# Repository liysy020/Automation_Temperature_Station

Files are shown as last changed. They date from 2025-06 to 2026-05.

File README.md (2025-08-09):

A central monitor to all network temperature and humidity sensors. This project suitable for Comms room monitoring in business and home users.

Sensors runs over wifi. They report data to the server. Depends on the sensor type it can monitor the temperatore and humidity of outdoor and indoor environment. It can also have LCD display showing current time as display on your desk (I uploaded a simple 3D print model for the desk display verson).

The project needs ESP32 running with micro Python. Tested 3x different types of outdoor and indoor temperature and humidity sensors. A 2 x 16 LCD display (Optional).

The sensor will need to register to the server in order to obtain a rendom generated API key. Communication running over SSL provides a secure channel.

Email alert can be switched on to get notification when sensor detected value outside of your comfort zone settings.

The sensor can also trigger external application such as exhaust fan when alert value met.

Last but not least the server keeps 4 months data history of the sensors. The data can be display in graph views.

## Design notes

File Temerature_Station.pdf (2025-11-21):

# Temperature and Humidity Station

# Introduction

There are 2 parts in this project. The first one is to build an LCD display clock using ESP32, LCD or OLED module with temperature sensors. It will show the current date time and the sensor information. You can build as many temperature monitors and put that round your house, garage, back yard etc with different types of IoT sensors as you design.

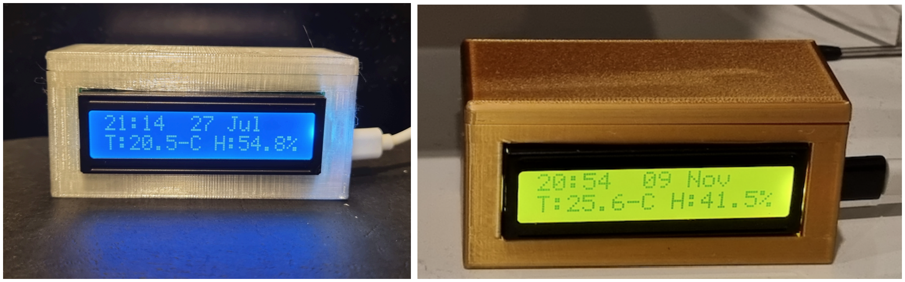
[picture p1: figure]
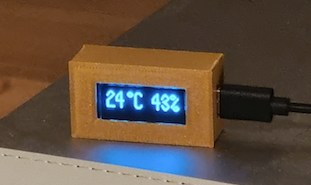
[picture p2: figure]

Part 2 is to build a server that collects all the sensor data and presents the latest sensor information such as temperature and humidity on a webserver. The ESP32 control board will send data every 2 mins using API calls. API Keys are stored on the server. Users can disable / enable any key resulting allow or reject the data from individual sensors. In addition, email notification can also be configured if temperature or humidity is outside of the comfort zone and trigger the power on/off of an electrical application via relay module

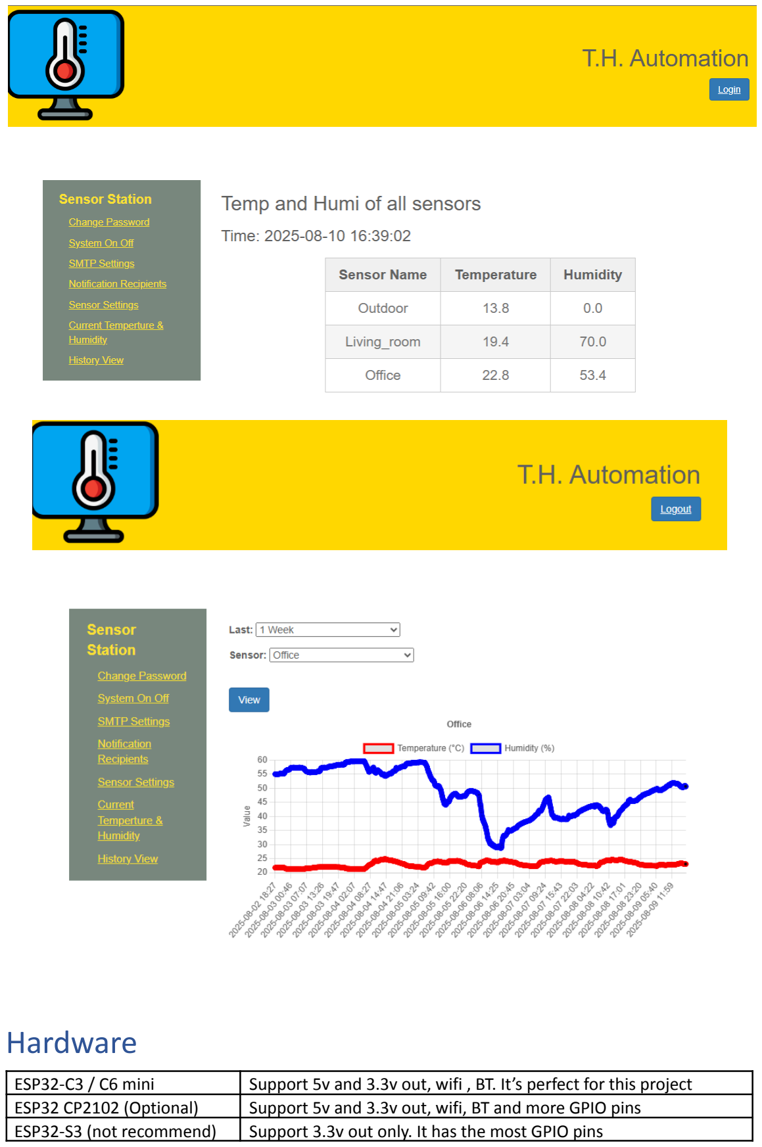
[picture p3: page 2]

# Hardware

ESP32-C3 / C6 mini | Support 5v and 3.3v out, wifi , BT. It’s perfect for this project
ESP32 CP2102 (Optional) | Support 5v and 3.3v out, wifi, BT and more GPIO pins
ESP32-S3 (not recommend) | Support 3.3v out only. It has the most GPIO pins

LCD1602 (Optional) | I2C 2 x 16 LCD display. 5V input
OLED 128 x 32 (Optional) | I2C 128 x32 OLES display. 3V input
DHT 11 (your pick) | Indoor temperature and humidity sensor / Cheap Input 3.3-5V / 0 – 50° C (± 2° C) / 20 – 90%RH (± 5%RH)
DHT 22 (your pick) | Temperature and humidity sensor Input 3.3-5V / -40 – 80 ° C (± 0.5° C) / 0 – 100%RH (± 2%)
DS18B20 (your pick) | Outdoor waterproof temperature sensor Input 3.3-5V / -55 – 125 ° C
Raspberry Pi 3b | 32Gb SD-card and Raspberry Lite OS
QC-3FF-S-Z | Power relay switch Input 5V / 10A 250vc or 15A 125vac

# Build the ESP32 and Sensors

## ESP32 Wiring - LCD and Temp Sensor

You will need to update the main.py file with the correct pin numbers according to the sensor and the LCD display you are going to use.

Below are the example values can be used / configured in the main.py for ESP32-CP2102 control board with LCD1602 display and DS18B20 temperature sensor

TEMP_PIN = 2

SDA_PIN = 21

SCL_PIN = 22

Another example for ESP32-3C, the SIG pin of the temperature sensor can go to ESP32’s GPIO 5. The LCD display SDA -> pin 8 and SCL -> pin 9

TEMP_PIN = 5

SDA_PIN = 8

SCL_PIN = 9

## Temperature Sensor Wiring (example)

DS18B20 can work on either 3v or 5v. I use 3v to reserve the 5v pin for LCD display

VCC <--> 3V, GND <--> Ground, SIG <--> GPIO 2

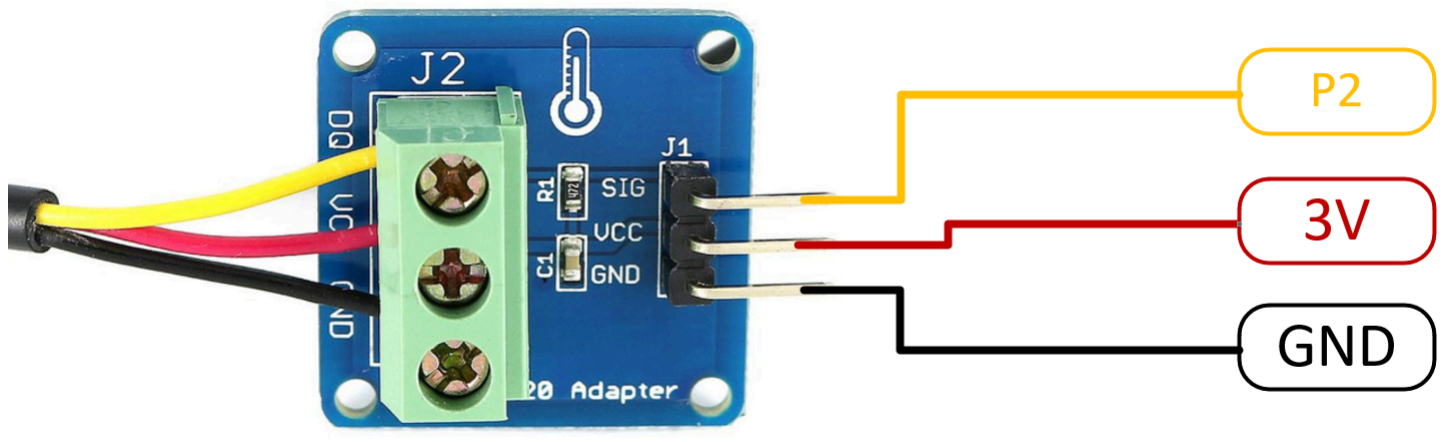
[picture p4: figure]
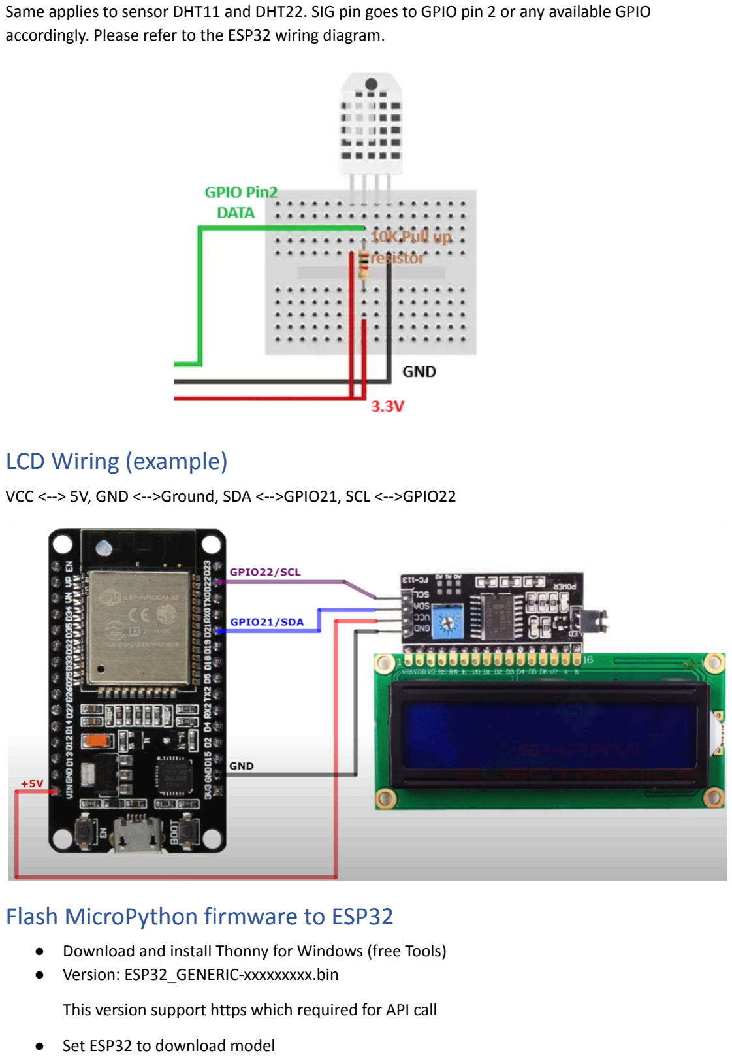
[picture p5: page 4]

Same applies to sensor DHT11 and DHT22. SIG pin goes to GPIO pin 2 or any available GPIO accordingly. Please refer to the ESP32 wiring diagram.

## LCD Wiring (example)

VCC <--> 5V, GND <-->Ground, SDA <-->GPIO21, SCL <-->GPIO22

## Flash MicroPython firmware to ESP32

- Download and install Thonny for Windows (free Tools)
- Version: ESP32_GENERIC-xxxxxxxxx.bin

This version support https which required for API call

- Set ESP32 to download model

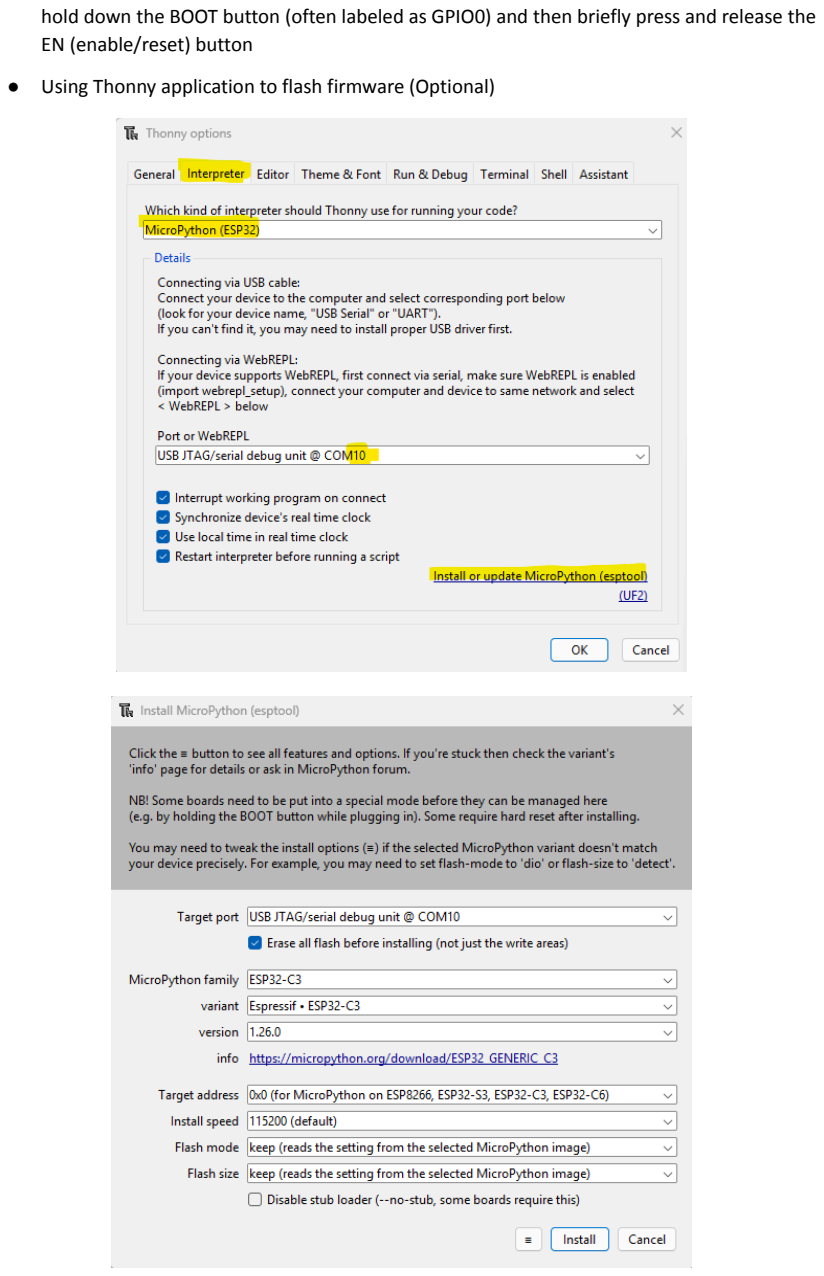
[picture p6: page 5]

hold down the BOOT button (often labeled as GPIO0) and then briefly press and release the EN (enable/reset) button

- Using Thonny application to flash firmware (Optional)

## Python code for ESP32

- Connect the ESP32 in Thonny

Tools Thonny Options Interpreter Select MicroPython (ES32) Select the Communication Port @ COM?? OK

- Upload <ESP32 Source Python> to ESP32

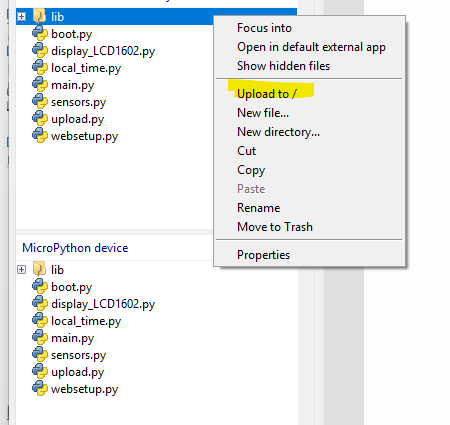
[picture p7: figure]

- Edit the main.py file to meet your need

TEMP_PIN, SDA_PIN and SCL_PIN

Day Light saving settings

Timezone settings

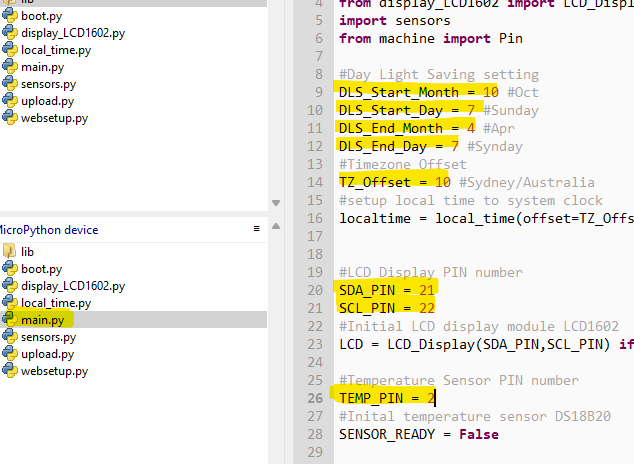
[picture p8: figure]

# Setup Django Web Server

## We can Ubuntu server VM or Raspberry Pi OS with SSH enable with full access

- Ubuntu server 24.04.01 (minimal footprint install / 2 CPU / 2G RAM / 20Gb Disk)
- If the system is running on a VM. Make sure all disk space has been used.

sudo lvextend -l +100%FREE /dev/ubuntu-vg/ubuntu-lv

sudo resize2fs /dev/mapper/ubuntu--vg-ubuntu--lv

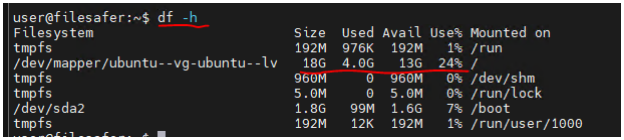
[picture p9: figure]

- Raspberry Pi 3 or 4B
- Install Raspberry Pi OS Lite (no Desktop needed)

## Install Django Framework and necessary Apps

sudo apt-get update

sudo apt-get install python3-django python3-pip python3-venv

- If you are using Ubuntu server 20.04 with minimal footprint installation (Optional)

sudo apt-get install nano cron iputils-ping sudo nano /etc/resolv.conf

add line: nameserver 8.8.8.8

## Create virtual environment and install Django

cd /

sudo mkdir Automation

sudo chmod 777 Automation

python3 -m venv Automation

cd Automation

source bin/activate

pip3 install Django

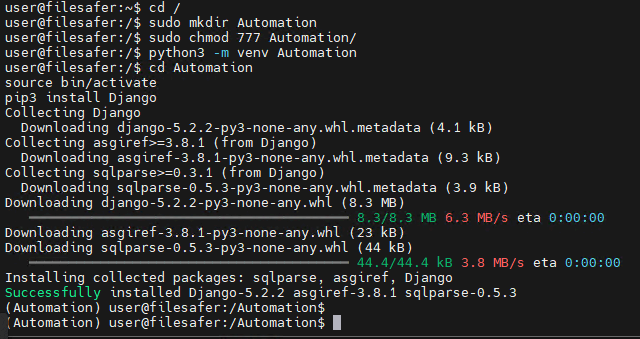
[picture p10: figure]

## Create web applications and install dependent libraries

- Perform below commands under directory /Automation within the virtual environment

django-admin startproject Thermometer .

python3 manage.py startapp Login

python3 manage.py startapp TempLog

pip3 install ipcalc six apscheduler pandas gunicorn netifaces SQLAlchemy

- Above process creates below folder structure

Thermometer

TempLog

Login

## Copy the source code files and setup

We will use sftp to copy the source files into created directories from above

If you are using a Windows computer you can use MoxaXterm free application to do this. Linux users can perform this task natively using Terminal.

- Start from the directory where you have downloaded the Django Source Code. SFTP to the server

cd /Automation

put -R *

cd TempLog

mv apps.py apps.py.tmp

cd ..

python3 manage.py makemigrations

python3 manage.py migrate

cd TempLog

mv apps.py.tmp apps.py

cd ..

chmod +x run.sh

- Create superuser for the Web App. This account is for you to login to the Web GUI

python3 manage.py createsuperuser

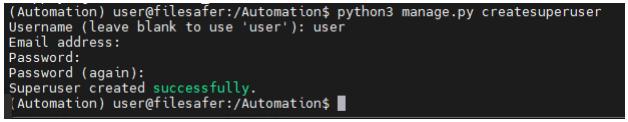
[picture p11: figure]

- Setup application auto-start (My ubuntu user account is called “user”. It used in @reboot code below)

sudo nano /etc/crontab

- add below line to the bottom and save / exit

@reboot user /bin/bash -c "/Automation/run.sh"

## Setup and configure the web server

- Setup Nginx (Engine X) as front-end web server
- Install Nginx sudo apt-get install nginx
- Setup web site in nginx by creating file “Django” in /etc/nginx/sites-available/

sudo nano /etc/nginx/sites-available/Django

- Copy below to the file, save and exit

server {

listen 443 ssl;

server_name <server FQDN or IP Address>;

ssl_certificate /Automation/Cert/server.crt;

ssl_certificate_key /Automation/Cert/server.key;

location / {

proxy_pass http://127.0.0.1:8000;

proxy_set_header Host $host;

proxy_set_header X-Real-IP $remote_addr;

proxy_set_header X-Forwarded-For $proxy_add_x_forwarded_for;

proxy_set_header X-Forwarded-Proto $scheme;

}

location /static/ {

alias /Automation/static/;

}

}

server {

listen 80;

server_name your.domain.or.ip;

return 301 https://$host$request_uri;

}

- Start Nginx
sudo ln -s /etc/nginx/sites-available/Django /etc/nginx/sites-enabled/ sudo nginx -t
sudo systemctl restart nginx

- CLI: nano /Automation/Thermometer/settings.py

update your server FQDN or IP address at line 30 in settings.py file

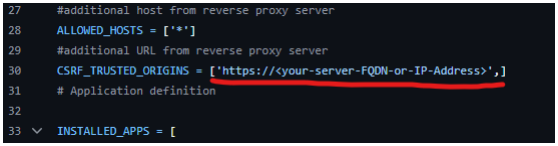
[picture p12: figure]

- Set the correct timezone (optional) before Rebooting the server.

sudo timedatectl set-timezone <local timezone such as Australia/Sydney>

sudo reboot now

o https://<your-server-ip-address>

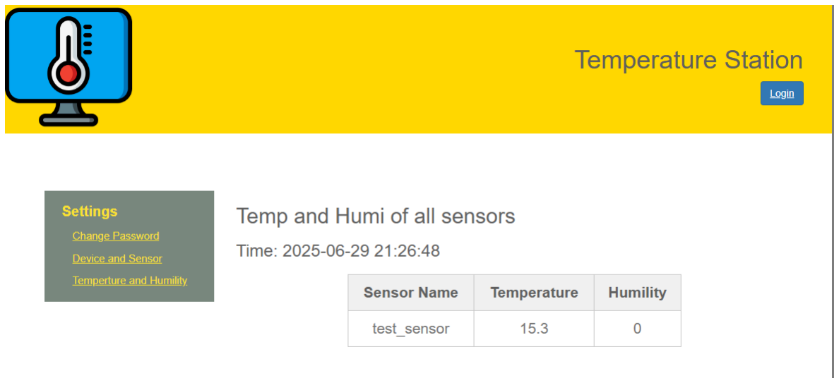
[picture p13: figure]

- Switch on email notifications

To enable email notification, you will need to set up SMTP settings and create Notification Recipients. You can select any sensor or All sensors you would like to receive notification when the sensor detected value outside of the comfort zone settings in your registered device.

To disable notification, you can either remove from the Recipients or set both of the Low and High values to the same value.

Last to switch on the notification, you will need to click on “Start” button from “System On Off”

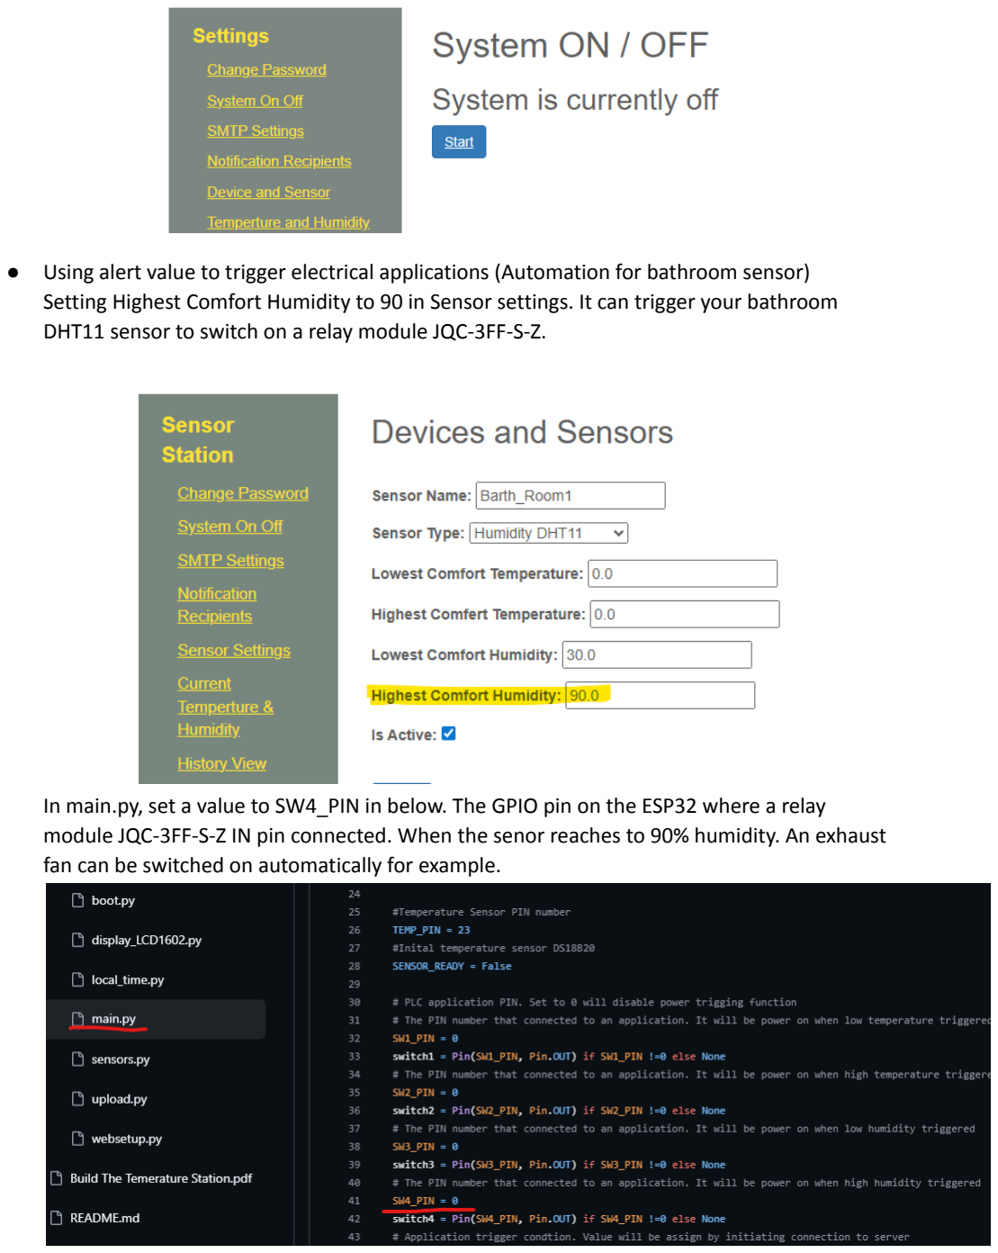
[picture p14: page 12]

- Using alert value to trigger electrical applications (Automation for bathroom sensor) Setting Highest Comfort Humidity to 90 in Sensor settings. It can trigger your bathroom DHT11 sensor to switch on a relay module JQC-3FF-S-Z.

In main.py, set a value to SW4_PIN in below. The GPIO pin on the ESP32 where a relay module JQC-3FF-S-Z IN pin connected. When the senor reaches to 90% humidity. An exhaust fan can be switched on automatically for example.

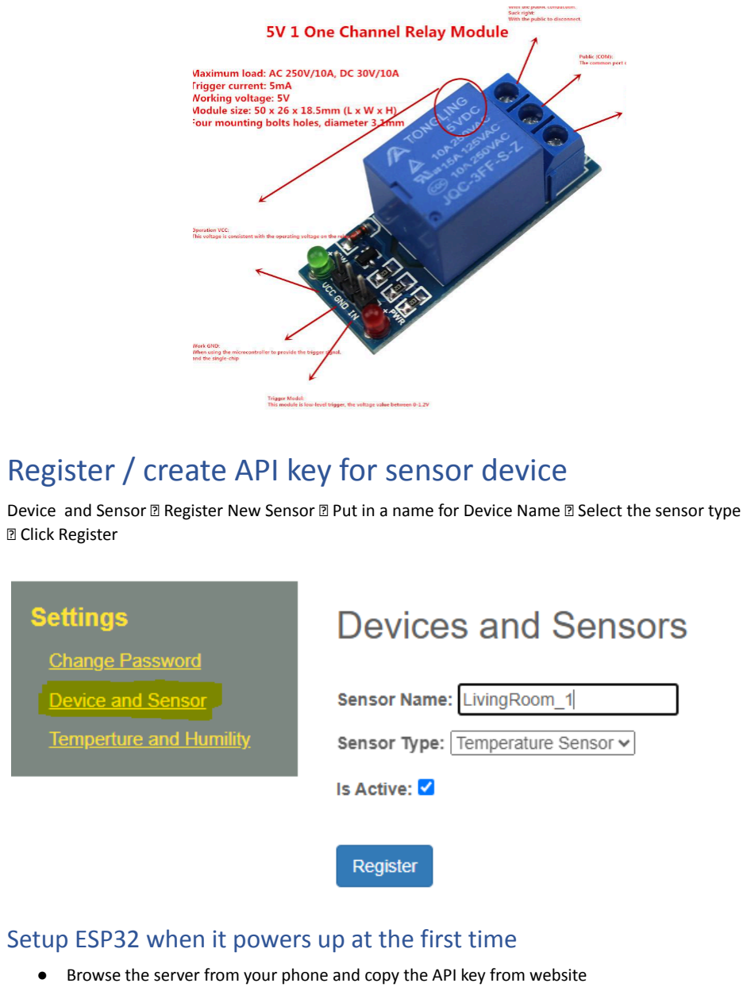
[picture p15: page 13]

# Register / create API key for sensor device

Device and Sensor Register New Sensor Put in a name for Device Name Select the sensor type Click Register

## Setup ESP32 when it powers up at the first time

- Browse the server from your phone and copy the API key from website

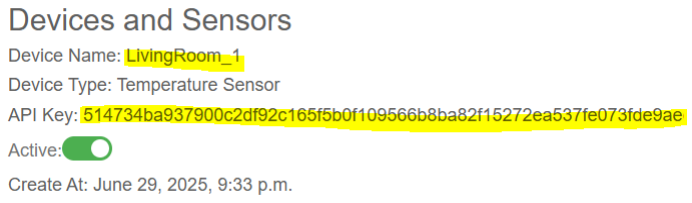
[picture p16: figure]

- Search SSID “Set-me-up” and connect with password as password. Browse http://192.168.0.1
- Fill in all necessary detail then click “Save and Reboot”
- Wifi name
- Wifi password
- Server IP
- Device name (as above)
- API Key (as above / paste)
- The ESP32 should reboot and connect to local wifi. You should see the display showing live information. The Website will should the temperature and humidity in 3 mins (average of last 3 mins)
- If the ESP32 can not connect to local wifi. The “set-me-up” network will show up again otherwise you will not see “Set-me-up” anymore.

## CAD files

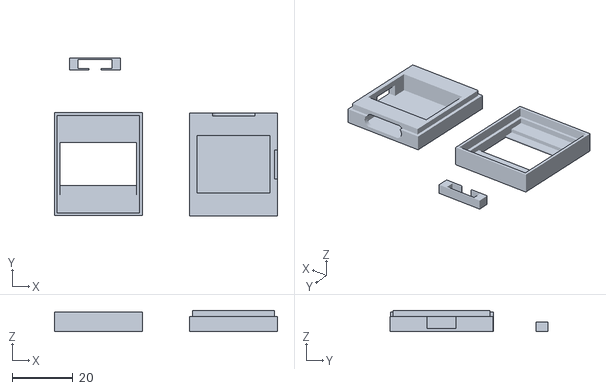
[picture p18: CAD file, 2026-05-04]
3D Models/ESP32C_OLED128_64_external sensor.stl
73.6 x 52.1 x 7.00

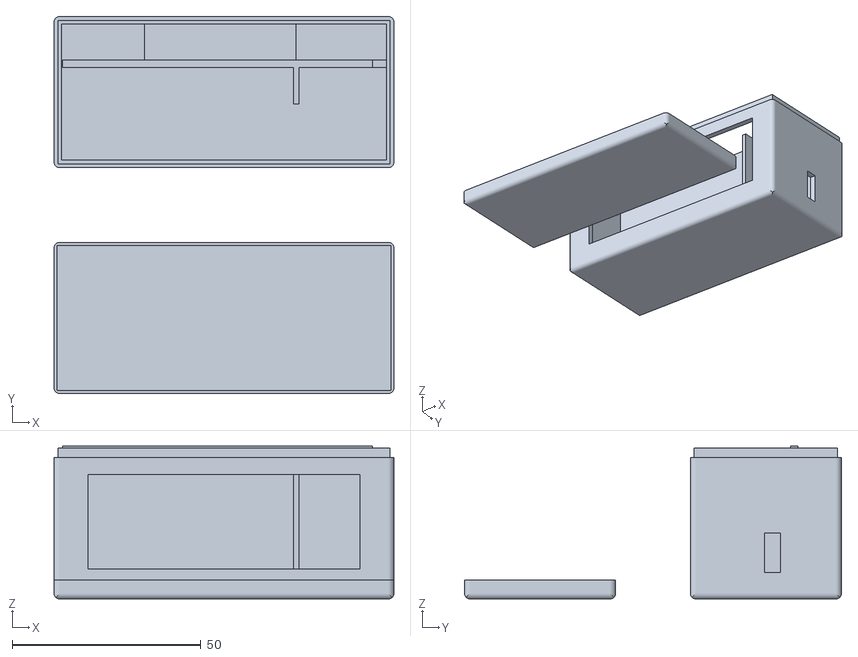
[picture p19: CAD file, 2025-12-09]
3D Models/3D Print case - ESP32-C3.stl
90.0 x 99.8 x 40.5

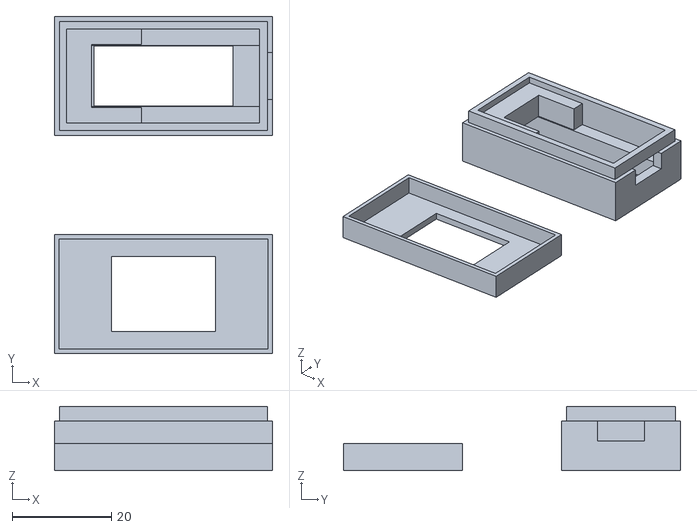
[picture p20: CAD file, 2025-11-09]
3D Models/ESP32C_OLED_DHT22.stl
44.0 x 68.0 x 13.0

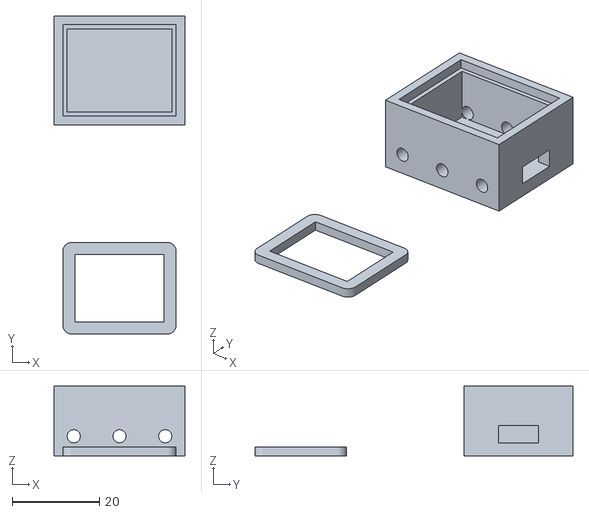
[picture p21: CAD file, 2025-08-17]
3D Models/Tempreture-EPS32-DHT22.stl
30.0 x 73.0 x 16.0

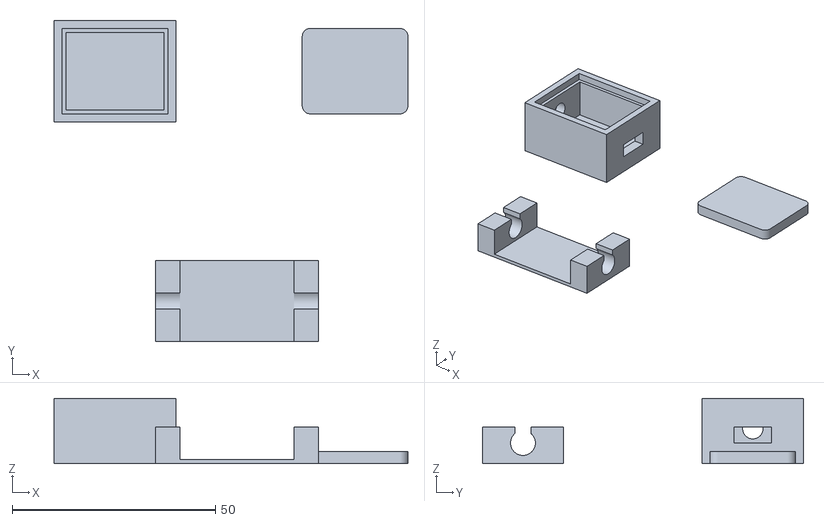
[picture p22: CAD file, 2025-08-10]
3D Models/Tempreture-EPS32-Outdoor.stl
87.0 x 79.0 x 16.0

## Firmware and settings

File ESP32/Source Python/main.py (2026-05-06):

import network, time, json
from upload import send
from local_time import local_time
from display_OLED1306 import OLED_128x32
from display_OLED1306 import OLED_128x64
from display_LCD1602 import LCD_Display
import sensors
from machine import Pin
##################### define attributes #########################
#Day Light Saving setting
DLS_Start_Month = 10 #Oct
DLS_Start_Day = 7 #Sunday
DLS_End_Month = 4 #Apr
DLS_End_Day = 7 #Synday
#Timezone Offset
TZ_Offset = 10 #Sydney/Australia
#setup local time to system clock
localtime = local_time(offset=TZ_Offset, dls_start=(DLS_Start_Month,DLS_Start_Day), dls_end=(DLS_End_Month,DLS_End_Day))

#Select one of the below display models
#Display PIN number
SDA_PIN = 0
SCL_PIN = 0
# Initial LCD display module LCD1602
#LCD = LCD_Display(SDA_PIN,SCL_PIN) if SDA_PIN != 0 and SCL_PIN != 0 else None

# Initial OLED display module 128x32
#LCD = OLED_128x32(SDA_PIN,SCL_PIN) if SDA_PIN != 0 and SCL_PIN != 0 else None

# Initial OLED display module 128x64
LCD = OLED_128x64(SDA_PIN,SCL_PIN) if SDA_PIN != 0 and SCL_PIN != 0 else None

#Temperature Sensor PIN number
TEMP_PIN = 0
# When the sensor placed too close to ESP chip
TEMP_OFFSET = 0
HUMI_OFFSET = 0
#Initalize temperature sensor
SENSOR_READY = False

# PLC application PIN. Set to 0 will disable power trigging function
# The PIN number that connected to an application. It will be power on when low temperature triggered
SW1_PIN = 0
switch1 = Pin(SW1_PIN, Pin.OUT) if SW1_PIN !=0 else None
# The PIN number that connected to an application. It will be power on when high temperature triggered
SW2_PIN = 0
switch2 = Pin(SW2_PIN, Pin.OUT) if SW2_PIN !=0 else None
# The PIN number that connected to an application. It will be power on when low humidity triggered
SW3_PIN = 0
switch3 = Pin(SW3_PIN, Pin.OUT) if SW3_PIN !=0 else None
# The PIN number that connected to an application. It will be power on when high humidity triggered
SW4_PIN = 0
switch4 = Pin(SW4_PIN, Pin.OUT) if SW4_PIN !=0 else None
# Application trigger condtion. Value will be assign by initiating connection to server 
T_Low = None
T_High = None
H_Low = None
H_High = None

#setup server detail
CONFIG_FILE = "initial.conf"
host = ''
DEVICE_NAME = ''
API_KEY = ''
port = 443
path = "/api/temperature/"
HOST_READY = False

#switch screen off at midnight. hours define in below. 0 means always_on
NIGHT_TIME_START = 0
NIGHT_TIME_FINISH = 0

########################## prgram start ################################
def is_night (t):
    hour = t[3]
    if NIGHT_TIME_START == 0 and NIGHT_TIME_FINISH == 0:
        return False
    if hour >= NIGHT_TIME_START or hour < NIGHT_TIME_FINISH:
        return True
    return False

try:
    with open(CONFIG_FILE, "r") as f:
        config = json.load(f)
        if not config:
            HOST_READY = False
        else:
            host = config.get("server")
            DEVICE_NAME = config.get("api_name")
            API_KEY = config.get("api_key")
            HOST_READY = True
except Exception as e:
    print ('set up server detail error:'+ str(e))
    HOST_READY = False

#setup sensor type by sending temp=0 and hum=0 to the server
#server will respond with value of sensor-type and PLC power trigger value
try:
    if not HOST_READY:
        SENSOR_READY = False
    else:
        respond = send (host=host, port=port, path=path, DEVICE_NAME=DEVICE_NAME, API_KEY=API_KEY)
        parts = respond.split(b'\r\n\r\n', 1)
        if len(parts) < 2:
            print("Invalid HTTP response: no body found")
        else:
            body_bytes = parts[1]
            body_str = body_bytes.decode('utf-8')
            body_json = json.loads(body_str)
            
            if TEMP_PIN == 0:
                SENSOR_READY = False
            else:
                if 'Temperature' in body_json.get("sensor-type"):
                    sensor = sensors.sensor_ds18x20(TEMP_PIN)
                elif 'Humidity' in body_json.get("sensor-type") and 'DHT11' in body_json.get("sensor-type"):
                    sensor = sensors.sensor_dht11(TEMP_PIN)
                elif 'Humidity' in body_json.get("sensor-type") and 'DHT22' in body_json.get("sensor-type"):
                    sensor = sensors.sensor_dht22(TEMP_PIN)
                SENSOR_READY = True

            T_Low = body_json.get("T_Low")
            T_High = body_json.get("T_High")
            H_Low = body_json.get("H_Low")
            H_High = body_json.get("H_High")
            
            if T_Low == 0 and T_High == 0:
                T_Low = None
                T_High = None
            if H_Low == 0 and H_High == 0:
                H_Low = None
                H_High = None
except Exception as e:
    print ('Failed to setup sensor type or server is not available '+str(e))
    SENSOR_READY = False

# print out device status:
if not LCD:
    print ('LCD is not configured!')
if not SENSOR_READY:
    print ('Sensor is not ready')
    
while_loop_counter = 12 #data will send to server every 2 mins while display refresh every 10 sec
while True:
    try:
        while_loop_counter = while_loop_counter -1
        str_temp = ''
        str_humi = ''
        temp = 0
        humi = 0
        if SENSOR_READY: # read sensor information
            data = sensor.read()
            print('senor readings: ' + str(data))
            try:
                if data:
                    temp, humi = data
                    temp = temp - TEMP_OFFSET
                    humi = humi - HUMI_OFFSET
            except:
                if data:
                    temp = data - TEMP_OFFSET
            str_temp = str(temp)
            str_humi = str(humi)
            if switch1 and T_Low:
                if temp <= float(T_Low): # Low temperature alert triggers switch 1 to power on
                    switch1.value(1)
                    print ('Low temperature trigger switch1 to power on')
                else:
                    switch1.value(0)
                    print ('switch 1 power off')
            if switch2 and T_High:
                if temp >= float(T_High): # High temperature alert trigger switch 2 to power on
                    switch2.value(1)
                    print ('High temperature trigger switch2 to power on')
                else:
                    switch2.value(0)
                    print ('switch 2 power off')
            if switch3 and H_Low:
                if humi <= float(H_Low): # Low Humidity alert trigger switch 3 to power on
                    switch3.value(1)
                    print ('Low Humidity trigger switch3 to power on')
                else:
                    switch3.value(0)
                    print ('switch 3 power off')
            if switch4 and H_High:
                if humi >= float(H_High): # High Humidity alert trigger switch4 to power on
                    switch4.value(1)
                    print ('High Humidity trigger switch4 to power on')
                else:
                    switch4.value(0)
                    print ('swtich 4 power off')
                
        time_string = localtime.get_display_time()
        t = localtime.get_time()
        if LCD:
            if (isinstance (LCD, OLED_128x32) or isinstance (LCD, OLED_128x64)) and t and LCD.lcd !=None: # for OLED display to print in big font
                if is_night (t): #Switch screen off by display white space
                    if isinstance (LCD, OLED_128x32):
                        LCD.display (line1 = ' ', line2 = ' ')
                    elif isinstance (LCD, OLED_128x64):
                        LCD.display (line1 = ' ', line2 = ' ', line3 = ' ', line4 = ' ')
                else:
                    if str_humi == '0': #temperture sensor
                        LCD.display (temp = str(int(temp)))
                    else: # temperture and humidity combined sensor
                        LCD.display (temp = str(int(temp)), humi = str(int(humi)))
            elif isinstance (LCD, LCD_Display) and t and LCD.lcd != None: # LCD display print datetime and temp/humi
                if is_night (t): #Switch off the backlight with display at the backgroup
                    if str_humi == '0':
                        LCD.display(line1 = time_string, line2 = "Temp:  "+str_temp+"C", backlight = False)
                    else:
                        LCD.display(line1 = time_string, line2 = "T:"+str_temp+"C H:"+str_humi+"%", backlight = False)
                else:
                    if str_humi == '0':
                        LCD.display(line1 = time_string, line2 = "Temp:  "+str_temp+ "°C")
                    else:
                        LCD.display(line1 = time_string, line2 = "T:"+str_temp+"°C H:"+str_humi+"%")
        if while_loop_counter <= 0 and HOST_READY and SENSOR_READY: # server is connected 
            while_loop_counter = 12 # reset the counter
            print('Data sent to server')
            send (host=host, port=port, path=path, DEVICE_NAME=DEVICE_NAME, API_KEY=API_KEY, temp=temp, humi=humi)                
    except Exception as e:
        print (str(e))
        continue
    time.sleep(10)

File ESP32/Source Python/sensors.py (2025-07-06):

import onewire, ds18x20
import machine, time

class sensor_ds18x20:
    def __init__(self, pin):
        # Setup DS18B20
        self.dat = machine.Pin(pin)
        self.ds = ds18x20.DS18X20(onewire.OneWire(self.dat))
        self.roms = self.ds.scan()
    
    def read(self):
        self.ds.convert_temp()
        time.sleep_ms(750)
        for rom in self.roms:
            return round(self.ds.read_temp(rom), 1)

import dht
from machine import Pin
class sensor_dht11:
    def __init__(self, pin):
        self.sensor = dht.DHT11(Pin(pin))

    def read(self, retries=3):
        for _ in range(retries):
            try:
                self.sensor.measure()
                temp = self.sensor.temperature()
                humi = self.sensor.humidity()
                return round(temp, 1), round(humi, 1)
            except OSError:
                pass
        return None
        
class sensor_dht22:
    def __init__(self, pin):
        self.sensor = dht.DHT22(Pin(pin))

    def read(self, retries=3):
        for _ in range(retries):
            try:
                self.sensor.measure()
                temp = self.sensor.temperature()
                humi = self.sensor.humidity()
                return round(temp, 1), round(humi, 1)
            except OSError:
                pass
        return None
        

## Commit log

2025-06-29 fixed the display time delay
    [main.py]
2025-06-30 fixed time sync errors
    [local_time.py, main.py]
2025-07-03 Add files via upload
    respond to ESP32 with the value of sensor type in the first api call (temp=0 and humi=0). so that ESP32 can handle different sensor dyniamically
2025-07-03 Add files via upload
    add initial device setup with webserver startup on ESP32.
    It provides option for user to put in wifi setting, server and API key detail instead of hardcode them in source code.
2025-07-03 Add files via upload
    ESP32 webserver for device initial setup
2025-07-06 Add sensor DHT11 and DHT22.
